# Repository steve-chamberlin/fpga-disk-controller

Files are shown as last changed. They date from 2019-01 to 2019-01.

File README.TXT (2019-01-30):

Compiled by Steve Chamberlin
steve@bigmessowires.com
January 28, 2019

//\\//\\//\\//\\//\\//\\//\\//\\//\\//\\//\\//\\//\\//\\//\\//\\//\\//\\//\\//\\

I'm sharing the FPGA disk controller design because I don't currently have the time or resources to pursue its further development on my own, but want the Apple II collector community to get the benefit of the progress I've made to date. 

See LICENSE.TXT for details on the license terms for this design.

The marks "Yellowstone", "BMOW", and "Big Mess o' Wires" are not covered by this license, and are reserved for my exclusive use. You are not permitted to use any of these words in the name of any clone or derivative products based on this design. You will need to choose a new name for your clone or derivative product.

//\\//\\//\\//\\//\\//\\//\\//\\//\\//\\//\\//\\//\\//\\//\\//\\//\\//\\//\\//\\

GROUND RULES
------------

Please don't send me detailed questions and requests for help with this design, or expect me to be your engineering consultant. I'm releasing the design to the community because I don't have time to pursue it myself. That means I can't work on it for you, either. The design is released as-is, with no promise of technical support. I may be able to answer general questions, but the rest is up to you.  

WHAT IS THIS?
-------------

Yellowstone is the code name for an Apple II disk controller card that's based on an FPGA, rather than using discrete logic chips and ROM chips. By reprogramming the FPGA, the card can be made to emulate various other disk controller cards made by Apple in the 1980s and 1990s. The work so far has focused on emulating an Apple Liron disk controller card, but it would also be easy to emulate a Disk II controller card. It's theoretically also possible to emulate a Disk 3.5 controller card, though this possibility has not been explored in detail.

WHAT'S LIRON?
-------------

The Liron disk controller was introduced by Apple in 1985. More formally known as the Apple II UniDisk 3.5 Controller, it's designed to work with a new generation of "smart" disk drives more sophisticated than the venerable Disk II 5.25 inch floppy drive. The smart disk port on the Liron is appropriately named the Smartport, and it can communicate with block-based storage devices such as the Unidisk 3.5 (an early 800K drive) and Smartport-based Apple II hard drives.

Why care about the Liron? The Apple IIc and Apple IIgs have integrated disk ports with built-in Smartport functionality, but for the earlier Apple II+ and IIe, the Liron is the only way to get a Smartport. For owners of the BMOW Floppy Emu disk emulator, having a Liron card makes it possible to use the Floppy Emu as an external hard drive for the II+ and IIe. Unfortunately finding a Liron is difficult, and although they occasionally turn up on eBay, they’re quite expensive. That makes cloning the Liron a desirable goal.

HOW IT WORKS
------------

The FPGA disk controller card is little more than an FPGA, a voltage regulator, and a set of level-shifting bus transceivers. The FPGA replaces all of the 7400-series discrete logic chips typically found on a disk controller card. Verilog (hardware description language) replacements for all of the 7400-series parts and other logic were written and programmed into the FPGA. This also includes a full Verilog implmentation of the Apple IWM chip. 

The FPGA also replaces the ROM chip containing the boot code for the card. The Apple II executes this code during power-up, and the code knows how to find and load sector 0 from the attached disk drive. The code was obtained from a ROM dump from a real Liron card.

The prototype card also includes a footprint for an 8-pin SPI flash memory chip. It is not used by the current FPGA code, and the chip can be omitted. The idea was that a small number of disk images could be stored in SPI flash memory, so the card could function both as a disk controller and as a disk emulator, but this was never implemented.

The card has a standard 10 x 2 pin disk connector on board. It can be connected directly to a BMOW Floppy Emu disk emulator, using a standard ribbon cable. But for a full Liron clone and connecton to a Unidisk 3.5, a DB-19 female connector is required. A design for a DB-19F adapter PCB is included here, and the adapter can be connected to the disk controller card with a short ribbon cable. The DB-19F is still available from surplus electronics suppliers in small quantities.

PROJECT STATUS
--------------

See https://www.bigmessowires.com/category/yellowstone/ for a complete history of work involving the FPGA disk controller.

The FPGA disk controller card was designed by Steve Chamberlin at Big Mess o' Wires during the summer of 2017, but the first prototype card wasn't built and tested until January 2018. The version 1.0 card had errors with the wiring for the output enable signal on one of the bus transceiver chips, and it required a few hand-soldered path wires to fix. After further development, the prototype card was demonstrated to work as a Liron clone, in both an Apple IIe enhanced computer and an Apple IIgs. It worked for controlling a real Unidisk 3.5 drive, as well as a BMOW Floppy Emu disk emulator configured for Smartport emulation mode.

Later testing discovered that the FPGA disk controller card worked reliably when it was the only card installed, but other cards were also present, it sometimes malfunctioned. The more other cards present, the worse the rate of errors became. This was diagnosed as a likely termination or contention problem on the Apple II data bus, and various fixes were tried unsuccessfully. After March 2018, I lost interest in researching the problem further, and no more work has occurred since then.

The design provided here is version 1.1, and it fixes the output enable problem from version 1.0.

WHERE TO START
--------------

Open the FPGA disk controller design (Liron clone) in EAGLE. Export Gerber files and send them to your favorite PCB fabricator. If desired, do the same for the DB19F adapter design.

Purchase the chips and other parts listed in the BOM. 

Assemble the card. I did it by hand, you can do it too. A syringe of solder paste and a hot plate or toaster oven works nicely.

Get a Lattice JTAG programmer or appropriate clone. Some clones don't handle 3.3V logic correctly. Maybe spend the extra money for a genuine Lattice programmer.

Install the Lattice Diamond software.

Apply 5V power to the card at jumper J4. Do not insert the card into your Apple II yet.

Program the FPGA with the bitstream for the Liron clone design - liron_fpgatop.jed

Insert the card in your Apple II. Remove any other cards that are present.

Connect a Smartport-compatible disk drive, such as a BMOW Floppy Emu disk emulator that's configured for Smartport emulation mode, or an Apple Unidisk 3.5 drive.

Turn on the Apple II. It should boot from the attached drive.

NEXT STEPS
----------

The bus termination or bus contention problem must be solved, in order to get a robust card that works smoothly when other cards are also present. See the blog posts from February-March 2018 for more details about what was already tried. A solution will require a person who's experienced at electronic design, and has appropriate test equipment such as an oscilloscope and logic analyzer.

The current design uses a Lattice MachXO2 1200HC FPGA, and a Lattice JTAG programmer (or compatible) is required for programming it. The XO2-1200HC has more logic resources than are actually necessary for the Liron clone design. The cheaper XO2-640 or XO2-256 could be substituted instead. They are mostly or entirely pin-compatible with the XO2-1200HC.

Programming the FPGA with a JTAG programmer is fine for development use, but end users are unlikely to have one. If reprogramming by the end user is desired (say to switch between Liron and Disk 3.5 emulation behaviors), a different method of FPGA programming will need to be developed.

FILES
-----

eagle/ - directory containing EAGLE designs for the FPGA disk controller card, the DB19F adapter, and a reverse-engineered schematic of the original Liron card.
eagle/FPGA disk controller/bom.xslx - bill of materials needed to assemble the card.
lattice/ - directory containing the Verilog and other code for the Liron clone design for the card.
yellowstone_blink/ - directory containing the Verilog and other code for a simple LED blink example. This can be used to verify that the FPGA is working.
yellowstone_blink_tcr.dir/ - directory containing some junk generated by the Lattice Diamond software.
disasm.asm, liron.asm - two different disassemblies of the original Liron card's boot ROM
LIRONALL.BIN - binary file with the original Liron card's boot ROM
rom-full-4k.mem - the Liron boot ROM in a format compatible with the Lattice Diamond software.
README.TXT - this file
LICENSE.TXT - details about the license for the design

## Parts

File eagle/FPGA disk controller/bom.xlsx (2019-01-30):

Designation | Description | Manufacturer Part Number | Acceptable Substitutes | Source 1 | Source 2 | notes
U1 | MachXO2 1200HC FPGA, 100-pin TQFP package | Lattice LCMXO2-1200HC-4TG100C | none | https://www.digikey.com/product-detail/en/lattice-semiconductor-corporation/LCMXO2-1200HC-4TG100C/220-1282-ND/2764797 |  | Could downsize to XO2-640 or XO2-256 if extra ROM space isn't needed. Confirm pinout differences.
U2 | SPI Flash memory, 8-pin SIOC package | Adesto AT25SF161-SSHD-T | similar | https://www.digikey.com/product-detail/en/adesto-technologies/AT25SF161-SSHD-T/1265-1230-1-ND/6124886 |  | Optional. Use for disk image storage, or ROM code if it's fast enough.
U3 | 300mA 3.3V LDO regulator, 5V input, SOT235 package | Micrel MIC5504-3.3YM5-TR | similar | https://www.digikey.com/product-detail/en/microchip-technology/MIC5504-3.3YM5-TR/576-4764-1-ND/4864028 | https://www.arrow.com/en/products/mic5504-3.3ym5-tr/microchip-technology
U4,U5,U6,U7 | 8-bit bus transceiver 74LVC245 | Nexperia 74LVC245ADB,118 | similar | https://www.digikey.com/product-detail/en/nexperia-usa-inc/74LVC245ADB,118/1727-3079-1-ND/946736
CON1 | IDC-20 male shrouded header | On Shore Technology 302-S201 | generic | http://www.digikey.com/product-detail/en/302-S201/ED10524-ND/2794235 | http://www.digikey.com/product-detail/en/SBH11-PBPC-D10-ST-BK/S9172-ND/1990065
J1 | 6x1 pin 0.1 inch male header, PTH | MC34743 | generic | http://www.newark.com/multicomp/mc34743/board-board-connector-header-24/dp/08N6756 | https://www.digikey.com/product-detail/en/sullins-connector-solutions/PRPC040SAAN-RC/S1011EC-40-ND/2775214 | Optional, JTAG port.
J2 | 4x1 pin 0.1 inch male header, PTH | MC34743 | generic | http://www.newark.com/multicomp/mc34743/board-board-connector-header-24/dp/08N6756 | https://www.digikey.com/product-detail/en/sullins-connector-solutions/PRPC040SAAN-RC/S1011EC-40-ND/2775214 | Optional, SPI port.
J3 | 8x1 pin 0.1 inch male header, PTH | MC34743 | generic | http://www.newark.com/multicomp/mc34743/board-board-connector-header-24/dp/08N6756 | https://www.digikey.com/product-detail/en/sullins-connector-solutions/PRPC040SAAN-RC/S1011EC-40-ND/2775214 | Optional, debug port.
J4 | 2x1 pin 0.1 inch male header, PTH | MC34743 | generic | http://www.newark.com/multicomp/mc34743/board-board-connector-header-24/dp/08N6756 | https://www.digikey.com/product-detail/en/sullins-connector-solutions/PRPC040SAAN-RC/S1011EC-40-ND/2775214 | Optional, 5V supply connector
D1 | LED, green, 0805 package, about 12 mcd | KP-2012SGC | generic | http://www.newark.com/kingbright/kp-2012sgc/led-green-1-25mm-x-1-3mm-15mcd/dp/31M5189 | https://www.digikey.com/product-detail/en/osram-opto-semiconductors-inc/LG-R971-KN-1/475-1410-1-ND/1802598 | debug LED
L1 | ferrite bead 0805 | BKP2125HS600-T | generic | https://www.digikey.com/product-detail/en/taiyo-yuden/BKP2125HS600-T/587-1932-1-ND/1465402
R1,R2 | 390 ohm resistor, 0805 package, 1/8W, 20% | RMCF0805JT390R | generic | https://www.digikey.com/product-detail/en/stackpole-electronics-inc/RMCF0805JT390R/RMCF0805JT390RCT-ND/1942549
R3 | 4.7K ohm resistor, 0805 package, 1/8W, 20% | RMCF0805JT4K70 | generic | https://www.digikey.com/product-detail/en/stackpole-electronics-inc/RMCF0805JT4K70/RMCF0805JT4K70CT-ND/1942570
R4,R5,R6 | 22K ohm resistor, 0805 package, 1/8W, 20% | RMCF0805JT22K0 | generic | https://www.digikey.com/product-detail/en/stackpole-electronics-inc/RMCF0805JT22K0/RMCF0805JT22K0CT-ND/1942581
C1-C12 | 0.1uF ceramic capacitor, 0805 package, 50V, 20% | CL21B104MBCNNNC | generic | https://www.digikey.com/product-detail/en/samsung-electro-mechanics-america-inc/CL21B104MBCNNNC/1276-2450-1-ND/3890536
C13-C18 | 0.01uF ceramic capacitor, 0805 package, 50V, 20% | CL21B103KBANNNC | generic | https://www.digikey.com/product-detail/en/samsung-electro-mechanics-america-inc/CL21B103KBANNNC/1276-1015-1-ND/3889101
C19,C20 | 10uF ceramic capacitor, 0805 package, 6.3V, 20% | CL21A106KQCLRNC | generic | http://www.newark.com/avx/08056d106kat2a/ceramic-capacitor-10uf-6-3v-x5r/dp/84K8398 | https://www.digikey.com/product-detail/en/samsung-electro-mechanics-america-inc/CL21A106KQCLRNC/1276-2405-1-ND/3890491
MISC1 | DB19-F |  |  |  |  | not required for Floppy Emu, but required for real drives
MISC2 | DB19-F adapter board |  |  |  |  | not required for Floppy Emu, but required for real drives

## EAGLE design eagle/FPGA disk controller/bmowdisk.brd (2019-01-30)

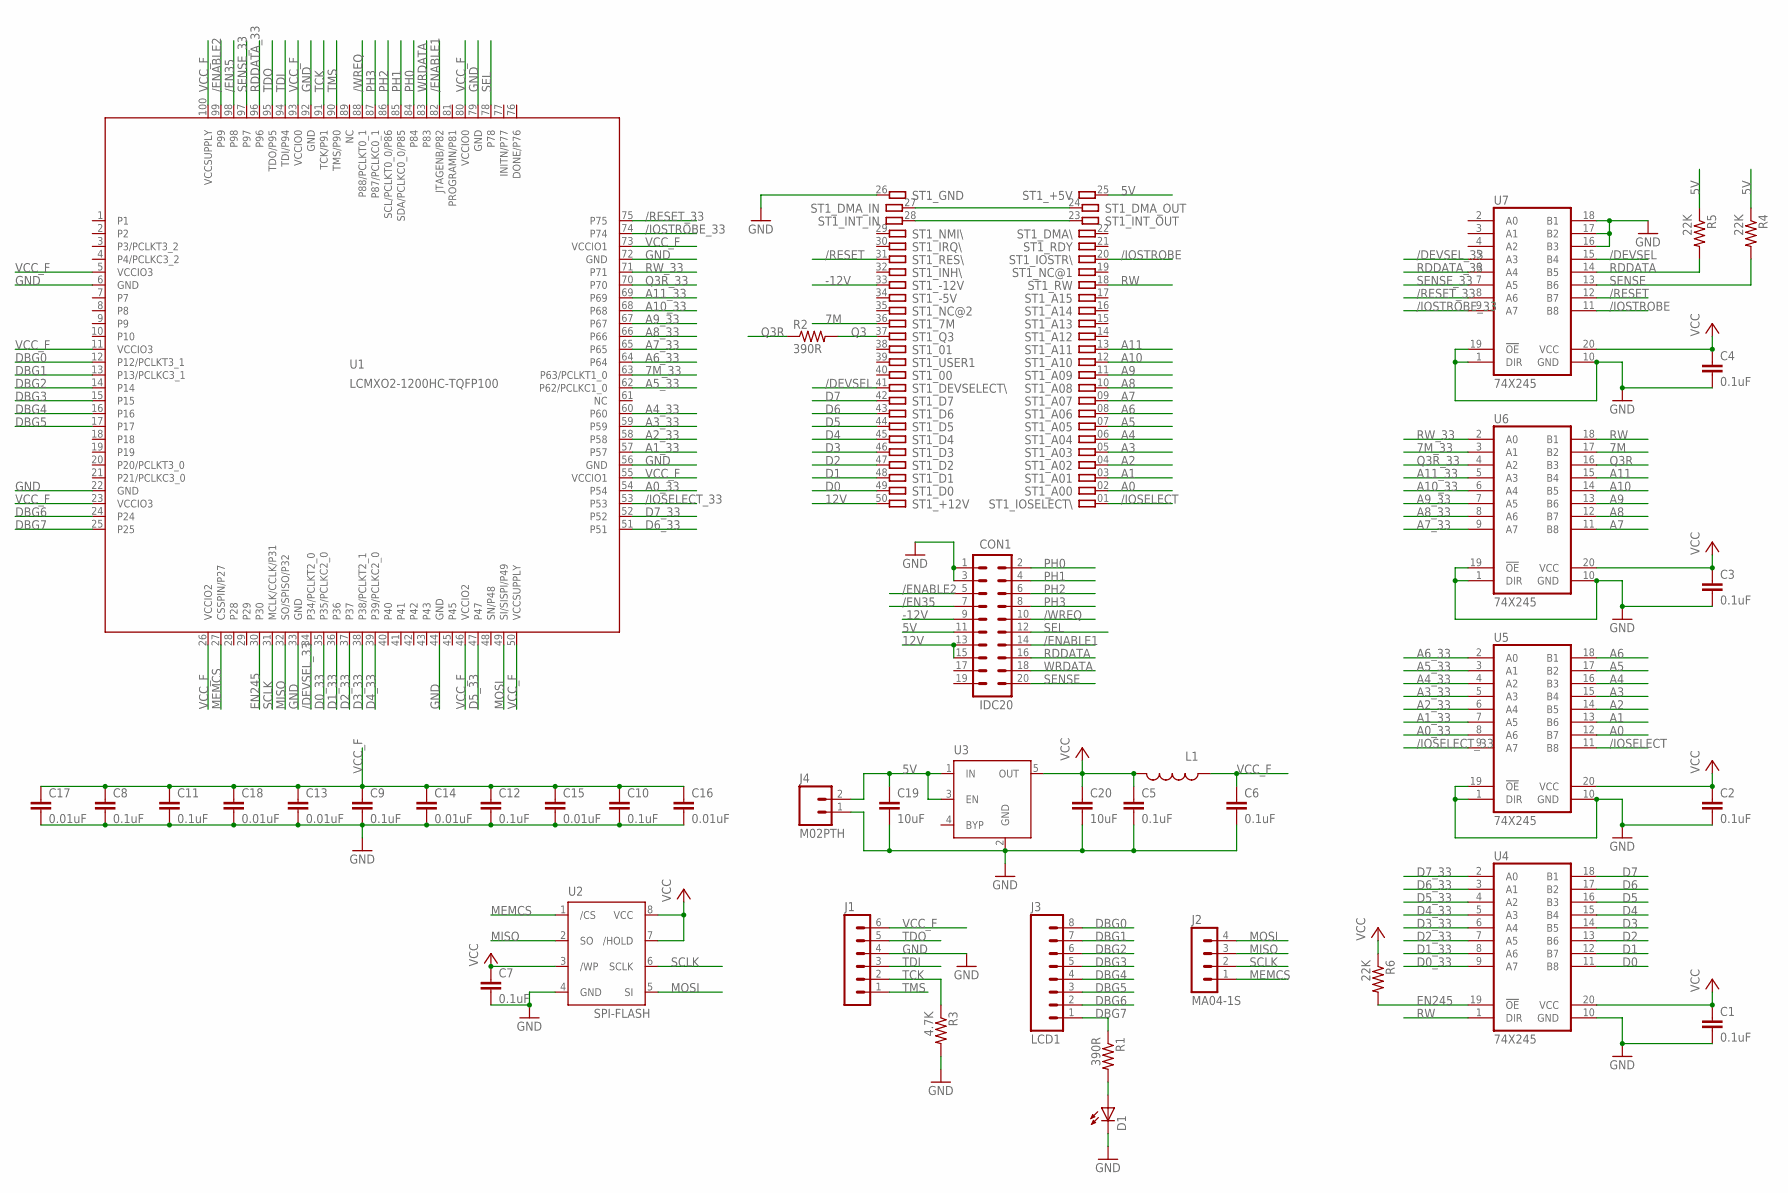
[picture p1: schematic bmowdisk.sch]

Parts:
C1, C2, C3, C4, C5, C6, C7, C8, C9, C10, C11, C12: 0.1uF; 0805
C13, C14, C15, C16, C17, C18: 0.01uF; 0805
C19, C20: 10uF; 0805
CON1: IDC20
D1: LEDCHIP-LED0805; CHIP-LED0805
J1: MA06-1NORMAL; MA06-1
J2: MA04-1S; MA04-1
J3: LCD1; 1X08
J4: M02PTH; 1X02
L1: INDUCTOR0805; 0805
R1, R2: 390R; 0805
R3: 4.7K; 0805
R4, R5, R6: 22K; 0805
ST1: A2-50PINMINI; A2-50PIN-MINI
U1: LCMXO2-1200HC-TQFP100; TQFP100
U2: SPI-FLASH; SOIC08
U3: MIC5219XX; SOT23-5
U4, U5, U6, U7: 74X245; SSOP20

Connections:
5V: C19.1, CON1.11, J4.2, R4.1, R5.1, ST1.25, U3.1 (IN), U3.3 (EN)
7M: ST1.36, U6.17 (B2)
7M_33: U1.63 (P63/PCLKT1_0), U6.3 (A1)
12V: CON1.13, CON1.15, ST1.50
-12V: CON1.9, ST1.33
/DEVSEL: ST1.41, U7.15 (B4)
/DEVSEL_33: U1.34 (P34/PCLKT2_0), U7.5 (A3)
/EN35: CON1.7, U1.98
/ENABLE1: CON1.14, U1.82 (JTAGENB/P82)
/ENABLE2: CON1.5, U1.99
/IOSELECT: ST1.01, U5.11 (B8)
/IOSELECT_33: U1.53, U5.9 (A7)
/IOSTROBE: ST1.20, U7.11 (B8)
/IOSTROBE_33: U1.74, U7.9 (A7)
/RESET: ST1.31, U7.12 (B7)
/RESET_33: U1.75, U7.8 (A6)
/WREQ: CON1.10, U1.88 (P88/PCLKT0_1)
A0: ST1.02, U5.12 (B7)
A0_33: U1.54, U5.8 (A6)
A1: ST1.03, U5.13 (B6)
A1_33: U1.57, U5.7 (A5)
A2: ST1.04, U5.14 (B5)
A2_33: U1.58, U5.6 (A4)
A3: ST1.05, U5.15 (B4)
A3_33: U1.59, U5.5 (A3)
A4: ST1.06, U5.16 (B3)
A4_33: U1.60, U5.4 (A2)
A5: ST1.07, U5.17 (B2)
A5_33: U1.62 (P62/PCLKC1_0), U5.3 (A1)
A6: ST1.08, U5.18 (B1)
A6_33: U1.64, U5.2 (A0)
A7: ST1.09, U6.11 (B8)
A7_33: U1.65, U6.9 (A7)
A8: ST1.10, U6.12 (B7)
A8_33: U1.66, U6.8 (A6)
A9: ST1.11, U6.13 (B6)
A9_33: U1.67, U6.7 (A5)
A10: ST1.12, U6.14 (B5)
A10_33: U1.68, U6.6 (A4)
A11: ST1.13, U6.15 (B4)
A11_33: U1.69, U6.5 (A3)
D0: ST1.49, U4.11 (B8)
D0_33: U1.35 (P35/PCLKC2_0), U4.9 (A7)
D1: ST1.48, U4.12 (B7)
D1_33: U1.36, U4.8 (A6)
D2: ST1.47, U4.13 (B6)
D2_33: U1.37, U4.7 (A5)
D3: ST1.46, U4.14 (B5)
D3_33: U1.38 (P38/PCLKT2_1), U4.6 (A4)
D4: ST1.45, U4.15 (B4)
D4_33: U1.39 (P39/PCLKC2_0), U4.5 (A3)
D5: ST1.44, U4.16 (B3)
D5_33: U1.47, U4.4 (A2)
D6: ST1.43, U4.17 (B2)
D6_33: U1.51, U4.3 (A1)
D7: ST1.42, U4.18 (B1)
D7_33: U1.52, U4.2 (A0)
DBG0: J3.8, U1.12 (P12/PCLKT3_1)
DBG1: J3.7, U1.13 (P13/PCLKC3_1)
DBG2: J3.6, U1.14
DBG3: J3.5, U1.15
DBG4: J3.4, U1.16
DBG5: J3.3, U1.17
DBG6: J3.2, U1.24
DBG7: J3.1, R1.1, U1.25
EN245: R6.2, U1.30, U4.19 (!OE)
GND: C1.2, C2.2, C3.2, C4.2, C5.2, C6.2, C7.2, C8.2, C9.2, C10.2, C11.2, C12.2, C13.2, C14.2, C15.2, C16.2, C17.2, C18.2, C19.2, C20.2, CON1.1, CON1.3, D1.C, J1.4, J4.1, R3.2, ST1.26, U1.6 (GND), U1.22 (GND), U1.33 (GND), U1.44 (GND), U1.56 (GND), U1.72 (GND), U1.79 (GND), U1.92 (GND), U2.4 (GND), U3.2 (GND), U4.10 (GND), U5.1 (DIR), U5.10 (GND), U5.19 (!OE), U6.1 (DIR), U6.10 (GND), U6.19 (!OE), U7.1 (DIR), U7.10 (GND), U7.16 (B3), U7.17 (B2), U7.18 (B1), U7.19 (!OE)
MEMCS: J2.1, U1.27 (CSSPIN/P27), U2.1 (/CS)
MISO: J2.3, U1.32 (SO/SPISO/P32), U2.2 (SO)
MOSI: J2.4, U1.49 (SI/SISPI/P49), U2.5 (SI)
unnamed: ST1.24, ST1.27
unnamed: ST1.23, ST1.28
unnamed: D1.A, R1.2
PH0: CON1.2, U1.84
PH1: CON1.4, U1.85 (SDA/PCLKC0_0/P85)
PH2: CON1.6, U1.86 (SCL/PCLKT0_0/P86)
PH3: CON1.8, U1.87 (P87/PCLKC0_1)
Q3: R2.2, ST1.37
Q3R: R2.1, U6.16 (B3)
Q3R_33: U1.70, U6.4 (A2)
RDDATA: CON1.16, R5.2, U7.14 (B5)
RDDATA_33: U1.96, U7.6 (A4)
RW: ST1.18, U4.1 (DIR), U6.18 (B1)
RW_33: U1.71, U6.2 (A0)
SCLK: J2.2, U1.31 (MCLK/CCLK/P31), U2.6 (SCLK)
SEL: CON1.12, U1.78
SENSE: CON1.20, R4.2, U7.13 (B6)
SENSE_33: U1.97, U7.7 (A5)
TCK: J1.2, R3.1, U1.91 (TCK/P91)
TDI: J1.3, U1.94 (TDI/P94)
TDO: J1.5, U1.95 (TDO/P95)
TMS: J1.1, U1.90 (TMS/P90)
VCC: C1.1, C2.1, C3.1, C4.1, C5.1, C7.1, C20.1, L1.2, R6.1, U2.3 (/WP), U2.7 (/HOLD), U2.8 (VCC), U3.5 (OUT), U4.20 (VCC), U5.20 (VCC), U6.20 (VCC), U7.20 (VCC)
VCC_F: C6.1, C8.1, C9.1, C10.1, C11.1, C12.1, C13.1, C14.1, C15.1, C16.1, C17.1, C18.1, J1.6, L1.1, U1.5 (VCCIO3), U1.11 (VCCIO3), U1.23 (VCCIO3), U1.26 (VCCIO2), U1.46 (VCCIO2), U1.50 (VCCSUPPLY), U1.55 (VCCIO1), U1.73 (VCCIO1), U1.80 (VCCIO0), U1.93 (VCCIO0), U1.100 (VCCSUPPLY)
WRDATA: CON1.18, U1.83

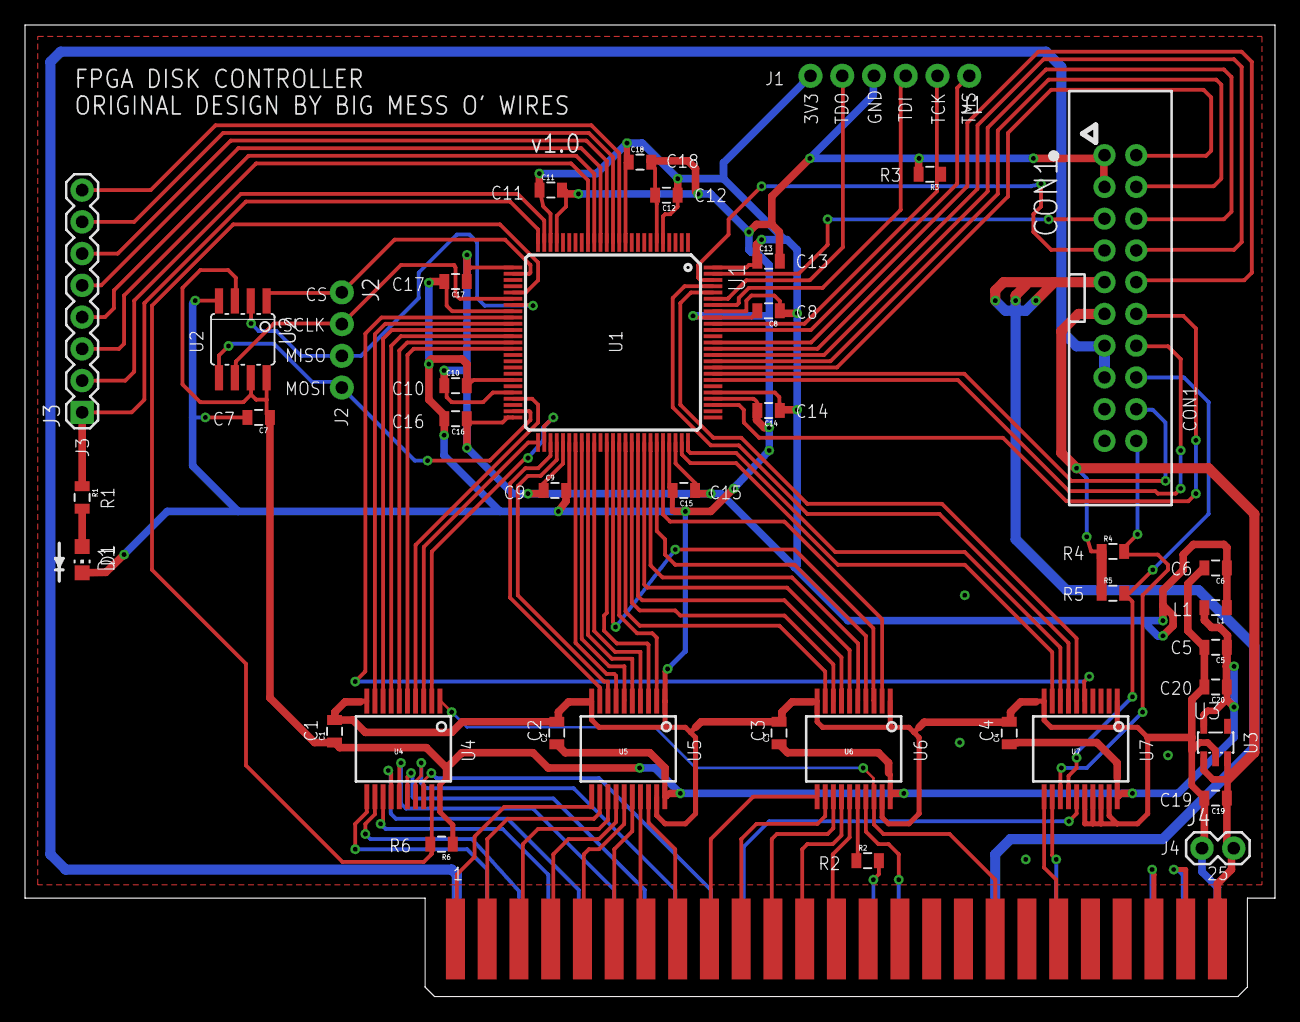
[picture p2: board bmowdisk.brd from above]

Board: 2 copper layers, 100.0 x 77.7 mm, 41 parts (0 on the bottom side), 95 nets.

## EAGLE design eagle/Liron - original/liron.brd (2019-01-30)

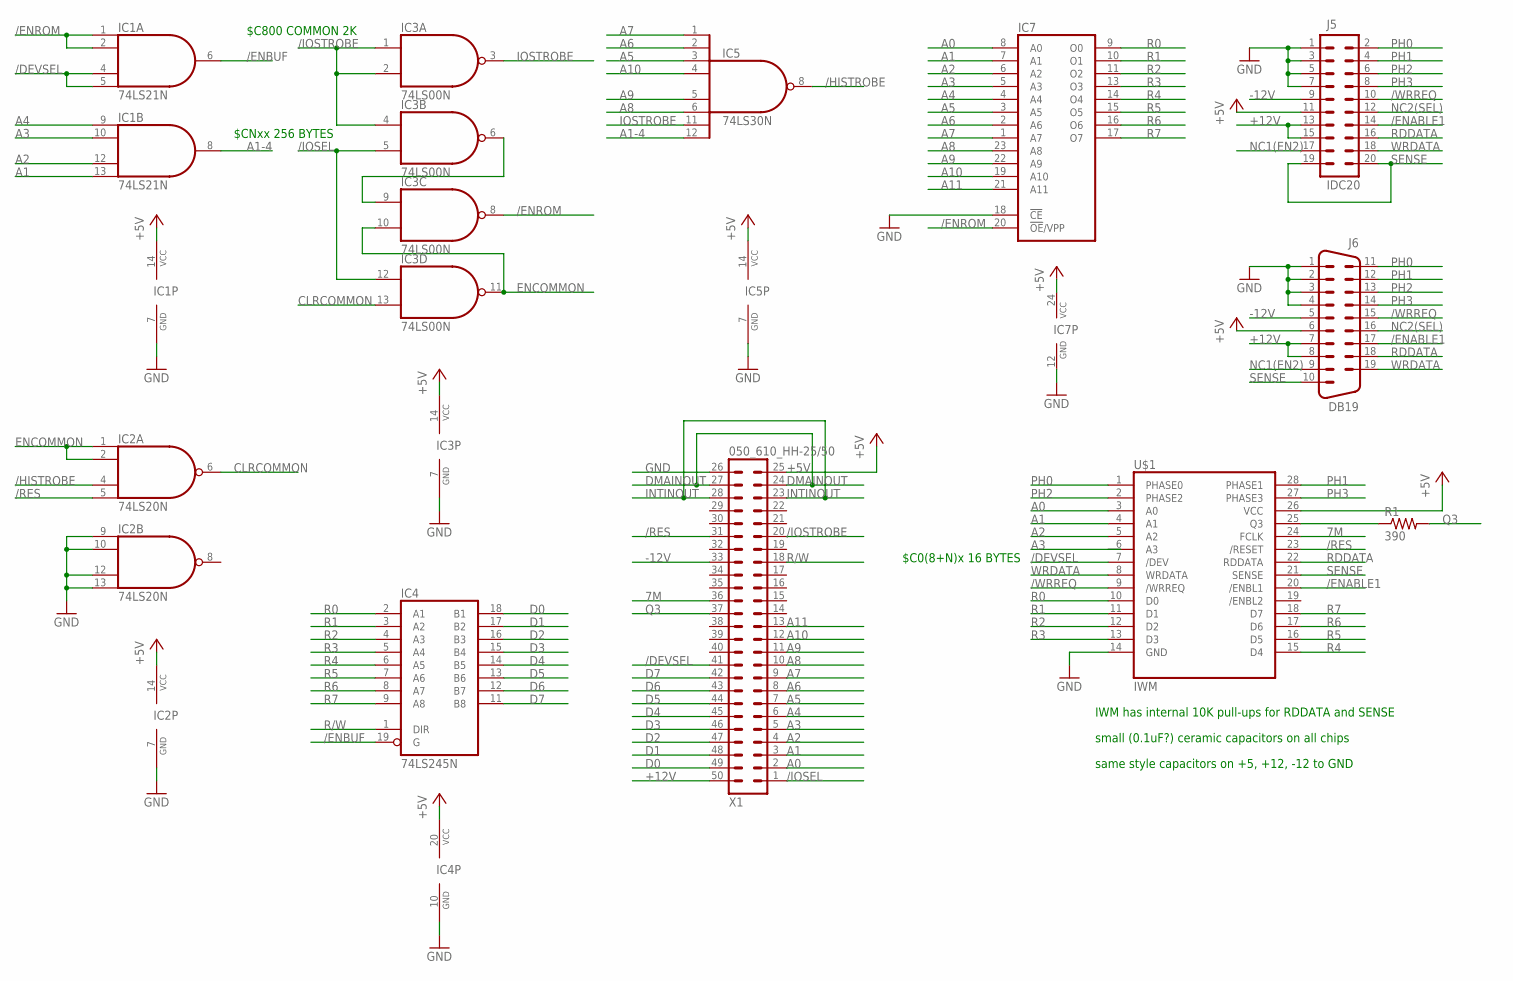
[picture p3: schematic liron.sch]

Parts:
IC1: 74LS21N; DIL14
IC2: 74LS20N; DIL14
IC3: 74LS00N; DIL14
IC4: 74LS245N; DIL20
IC5: 74LS30N; DIL14
IC7: 2732; DIL24
J5: IDC20
J6: DB19; DB19EDGE
R1: 390; 0805
U$1: IWM; DIL28
X1: 050_610_HH-25/50

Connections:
7M: U$1.24 (FCLK), X1.36 (40)
+5V: IC1.14 (VCC), IC2.14 (VCC), IC3.14 (VCC), IC4.20 (VCC), IC5.14 (VCC), IC7.24 (VCC), J5.11, J6.6, U$1.26 (VCC), X1.25
+12V: J5.13, J5.15, J6.7, J6.8, X1.50 (26)
-12V: J5.9, J6.5, X1.33 (43)
/DEVSEL: IC1.4 (I2), IC1.5 (I3), U$1.7 (/DEV), X1.41 (35)
/ENABLE1: J5.14, J6.17, U$1.20 (/ENBL1)
/ENBUF: IC1.6 (O), IC4.19 (G)
/ENROM: IC1.1 (I0), IC1.2 (I1), IC3.8 (O), IC7.20 (!OE!/VPP)
/HISTROBE: IC2.4 (I2), IC5.8 (O)
/IOSEL: IC3.5 (I1), IC3.12 (I0), X1.1
/IOSTROBE: IC3.1 (I0), IC3.2 (I1), IC3.4 (I0), X1.20
/RES: IC2.5 (I3), U$1.23 (/RESET), X1.31 (45)
/WRREQ: J5.10, J6.15, U$1.9 (/WRREQ)
A0: IC7.8 (A0), U$1.3 (A0), X1.2
A1: IC1.13 (I3), IC7.7 (A1), U$1.4 (A1), X1.3
A1-4: IC1.8 (O), IC5.12 (I7)
A2: IC1.12 (I2), IC7.6 (A2), U$1.5 (A2), X1.4
A3: IC1.10 (I1), IC7.5 (A3), X1.5
A4: IC1.9 (I0), IC7.4 (A4), X1.6
A5: IC5.3 (I2), IC7.3 (A5), X1.7
A6: IC5.2 (I1), IC7.2 (A6), X1.8
A7: IC5.1 (I0), IC7.1 (A7), X1.9
A8: IC5.6 (I5), IC7.23 (A8), X1.10
A9: IC5.5 (I4), IC7.22 (A9), X1.11
A10: IC5.4 (I3), IC7.19 (A10), X1.12
A11: IC7.21 (A11), X1.13
CLRCOMMON: IC2.6 (O), IC3.13 (I1)
D0: IC4.18 (B1), X1.49 (27)
D1: IC4.17 (B2), X1.48 (28)
D2: IC4.16 (B3), X1.47 (29)
D3: IC4.15 (B4), X1.46 (30)
D4: IC4.14 (B5), X1.45 (31)
D5: IC4.13 (B6), X1.44 (32)
D6: IC4.12 (B7), X1.43 (33)
D7: IC4.11 (B8), X1.42 (34)
DMAINOUT: X1.24, X1.27 (49)
ENCOMMON: IC2.1 (I0), IC2.2 (I1), IC3.10 (I1), IC3.11 (O)
GND: IC1.7 (GND), IC2.7 (GND), IC2.9 (I0), IC2.10 (I1), IC2.12 (I2), IC2.13 (I3), IC3.7 (GND), IC4.10 (GND), IC5.7 (GND), IC7.12 (GND), IC7.18 (!CE), J5.1, J5.3, J5.5, J5.7, J6.1, J6.2, J6.3, J6.4, U$1.14 (GND), X1.26 (50)
INTINOUT: X1.23, X1.28 (48)
IOSTROBE: IC3.3 (O), IC5.11 (I6)
unnamed: IC3.6 (O), IC3.9 (I0)
unnamed: R1.1, U$1.25 (Q3)
NC1(EN2): J5.17, J6.9
NC2(SEL): J5.12, J6.16
PH0: J5.2, J6.11, U$1.1 (PHASE0)
PH1: J5.4, J6.12, U$1.28 (PHASE1)
PH2: J5.6, J6.13, U$1.2 (PHASE2)
PH3: J5.8, J6.14, U$1.27 (PHASE3)
Q3: R1.2, X1.37 (39)
R0: IC4.2 (A1), IC7.9 (O0), U$1.10 (D0)
R1: IC4.3 (A2), IC7.10 (O1), U$1.11 (D1)
R2: IC4.4 (A3), IC7.11 (O2), U$1.12 (D2)
R3: IC4.5 (A4), IC7.13 (O3), U$1.13 (D3)
R4: IC4.6 (A5), IC7.14 (O4), U$1.15 (D4)
R5: IC4.7 (A6), IC7.15 (O5), U$1.16 (D5)
R6: IC4.8 (A7), IC7.16 (O6), U$1.17 (D6)
R7: IC4.9 (A8), IC7.17 (O7), U$1.18 (D7)
R/W: IC4.1 (DIR), X1.18
RDDATA: J5.16, J6.18, U$1.22 (RDDATA)
SENSE: J5.19, J5.20, J6.10, U$1.21 (SENSE)
WRDATA: J5.18, J6.19, U$1.8 (WRDATA)

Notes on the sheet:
$C800 COMMON 2K
$CNxx 256 BYTES
$C0(8+N)x 16 BYTES
small (0.1uF?) ceramic capacitors on all chips
same style capacitors on +5, +12, -12 to GND
IWM has internal 10K pull-ups for RDDATA and SENSE

Board: 2 copper layers, 11 parts (0 on the bottom side), 61 nets, no tracks yet.

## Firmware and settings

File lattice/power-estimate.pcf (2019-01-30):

[[Info]]
_PARENT: none
_FAMILY: xo2c00
_FILE_FORMAT: 1.00
_DATA_VALUES: 1.00
_STATUS: Advanced

[[Project]]
DesignName: top
Family: MachXO2
Device: LCMXO2-640HC
Package: TQFP100
Operating: Commercial
Version: 8.0
Performance: -4
PartName: LCMXO2-640HC-4TG100C

[[Settings]]
EstimationMode: Medium
ProcessType: Typical
SoftwareMode: Calculation
TempAmbX: Ambient Temperature
SectionY: Total Power
SectionX: Vcc
SectionLowerLimit: 0.0000
SectionUpperLimit: 0.0000
SectionResolution: 0.0000
TempAmbY: Ambient Temperature
TempAmbLowerLimit: -30.0000
TempAmbUpperLimit: 115.0000
TempAmbResolution: 29.0000
FreqY: Total Power
FreqX: No Clocks Found!
FreqLowerLimit: 10.0000
FreqUpperLimit: 100.0000
FreqAmbResolution: 20.0000
PowerMode: Normal
DisableBandgap: false
DisablePor: false
DisableDll: false
DisableOsc: false
DisablePLL0: false
DisablePLL1: false
DisableInRd0: false
DisableInRd1: false
DisableInRd2: false
DisableInRd3: false
DisableInRd4: false
DisableInRd5: false
DisableInRd6: false
DisableInRd7: false
EnablePg0: false
EnablePg1: false
EnablePg2: false
EnablePg3: false
EnablePg4: false
EnablePg5: false
EnablePg6: false
EnablePg7: false
DisableLVDS: false
DisableLVDS1: false
DisableLVDS2: false
DisableLVDS3: false
DisableLVDS4: false
DisableLVDS5: false
DisableLVDS6: false
DisableLVDS7: false

[[Thermal]]
Airflow: 200 LFM
AmbientTemperature: 25
CustomThetaSA: -1
JunctionTemperature: 25.19
MaxSafeAmbient: 84.67
ThetaBA: 10.0
ThetaCS: 0
ThetaEffective: 16.65
ThetaJA: 20.59
ThetaJB: 12.88
ThetaJC: 0
ThetaSA: -1
UserThetaBA: No
UserThetaCS: No
UserThetaEffective: No
UserThetaJA: No
UserThetaJB: No
UserThetaJC: No
UserThetaSA: No
thetaBoard: Medium Board
thetaHeatSink: No Heat Sink
thetaOption: ThermalModels

[[VDPM]]
Supply = Voltage, DPM
Vcc = 3.300, 1.00
Vccio 3.3 = 3.300, 1.00
Vccio 2.5 = 2.500, 1.00
Vccio 1.8 = 1.800, 1.00
Vccio 1.5 = 1.500, 1.00
Vccio 1.2 = 1.200, 1.00

[[Logic]]
Clk = F, AF, LUT, RAM, RIPPLE, REG, X0, X1, X2, X6, ISB, ISBLUT, ISBCE, ISBLSR, ISBM, ISBCLK
COMBINATORIAL = 7.0000, 10.0000^d^, 56, 0, 0, 0, 59, 23, 123, 31, 119, 70, 16, 6, 9, 2
_devsel_c = 1.0000, 10.0000^d^, 15, 0, 0, 8, 18, 18, 55, 9, 61, 49, 8, 3, 1, 8
fclk_c = 7.0000, 10.0000^d^, 43, 0, 0, 35, 50, 25, 66, 18, 301, 290, 5, 5, 1, 23

[[Clocks]]
Clk = F, Duty, Pfeed, Ptrunk, Pspine, Ptap, Pbranch, Strunk, Sspine, Stap, Sbranch, Etb, Ebg, Elr
_devsel_c = 1.0000, 50.0000, 0, 0, 0, 0, 0, t4_1, c13_1, r4_2, b_10, 0, 0, 0
fclk_c = 7.0000, 50.0000, 0, t3_1, s13_1, p13_1_p17_1, c14_4_c17_4, 0, 0, 0, b_0, 0, 0, 0

[[Input Output]]
Clk = _Type, _Mode, F, AF, IP, OP, PG, Cload, Bank, _ActualMode, _Pull, X0, X1, X2, X6, ISB
COMBINATORIAL = LVCMOS25, none, 7.0000, 10.0000^d^, 4, 0, OFF, 5, 2, none, DOWN, 0, 0, 0, 0, 0
COMBINATORIAL = LVCMOS25, none, 7.0000, 10.0000^d^, 11, 0, OFF, 5, 1, none, DOWN, 0, 0, 0, 0, 0
COMBINATORIAL = LVCMOS25, none, 7.0000, 10.0000^d^, 5, 0, OFF, 5, 0, none, DOWN, 0, 0, 0, 0, 0
COMBINATORIAL = LVCMOS25-8mA-SLEW:SLOW, none, 7.0000, 10.0000^d^, 0, 2, N/A, 5, 2, none, DOWN, 0, 0, 0, 0, 0
_devsel_c = LVCMOS25-8mA-SLEW:SLOW, none, 1.0000, 10.0000^d^, 0, 1, N/A, 5, 1, none, DOWN, 0, 0, 0, 0, 0
_devsel_c = LVCMOS25-8mA-SLEW:SLOW, none, 1.0000, 10.0000^d^, 0, 2, N/A, 5, 0, none, DOWN, 0, 0, 0, 0, 0
_devsel_c = LVCMOS25-8mA-SLEW:SLOW, none, 1.0000, 10.0000^d^, 0, 4, N/A, 5, 3, none, DOWN, 0, 0, 0, 0, 0
_devsel_c = LVCMOS25-8mA-SLEW:SLOW, none, 1.0000, 10.0000^d^, 0, 10, N/A, 5, 2, none, DOWN, 0, 0, 0, 0, 0
_devsel_c = LVCMOS25, none, 1.0000, 10.0000^d^, 1, 0, OFF, 5, 3, none, UP, 0, 0, 0, 0, 0
fclk_c = LVCMOS25-8mA-SLEW:SLOW, none, 7.0000, 10.0000^d^, 0, 1, N/A, 5, 0, none, DOWN, 0, 0, 0, 0, 0
fclk_c = LVCMOS25, none, 7.0000, 10.0000^d^, 1, 0, OFF, 5, 2, none, DOWN, 0, 0, 0, 0, 0

[[Bidi]]
ClkInpName = _Type, _Mode, InpF, InpAF, Bidi, PG, ClkOutName, OutF, OutAF, Duty, Cload, Bank, _ActualMode, _Pull, X0, X1, X2, X6, ISB
COMBINATORIAL = LVCMOS25-8mA-SLEW:SLOW, none, 7.0000, 10.0000^d^, 5, OFF, N/A, 0.0000^d^, 10.0000^d^, 50, 5, 1, none, DOWN, 0, 0, 0, 0, 0
_devsel_c = LVCMOS25-8mA-SLEW:SLOW, none, 1.0000, 10.0000^d^, 3, OFF, N/A, 0.0000^d^, 10.0000^d^, 50, 5, 1, none, DOWN, 0, 0, 0, 0, 0

[[Bank Voltage]]
Bank = Voltage, InRD, LVDSO, PG
0 = Vccio 2.5, No, No, OFF
1 = Vccio 2.5, No, N/A, OFF
2 = Vccio 2.5, No, N/A, OFF
3 = Vccio 2.5, No, N/A, OFF

[[Termination]]
_Type = IP, OP, Bidi, Duty, Bank, Rth, Vth
LVCMOS25 = 5, 0, 0, 0.0, 2, 1.0E12, 0
LVCMOS25 = 11, 0, 0, 0.0, 1, 1.0E12, 0
LVCMOS25 = 5, 0, 0, 0.0, 0, 1.0E12, 0
LVCMOS25-8mA-SLEW:SLOW = 0, 12, 0, 0.0, 2, 1.0E12, 0
LVCMOS25-8mA-SLEW:SLOW = 0, 1, 8, 31.8, 1, 1.0E12, 0
LVCMOS25-8mA-SLEW:SLOW = 0, 3, 0, 0.0, 0, 1.0E12, 0
LVCMOS25-8mA-SLEW:SLOW = 0, 4, 0, 0.0, 3, 1.0E12, 0
LVCMOS25 = 1, 0, 0, 0.0, 3, 1.0E12, 0

[[SP RAM]]
Clk = EBR, F, AF, _Type, X0, X1, X2, X6, ISB

[[DP RAM]]
RdClk = RdF, RdAF, EBR, WrClk, WrF, WrAF, _TypeA, _TypeB, X0, X1, X2, X6, ISB
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

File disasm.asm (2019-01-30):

L0000   = $0000
L0001   = $0001
L0002   = $0002
L0003   = $0003
L0024   = $0024
L0025   = $0025
L0040   = $0040
L0041   = $0041
L0042   = $0042
L0043   = $0043
L0044   = $0044
L0045   = $0045
L0046   = $0046
L0047   = $0047
L0048   = $0048
L0049   = $0049
L004B   = $004B
L004C   = $004C
L004D   = $004D
L004E   = $004E
L004F   = $004F
L0050   = $0050
L0051   = $0051
L0052   = $0052
L0053   = $0053
L0054   = $0054
L0055   = $0055
L0056   = $0056
L0057   = $0057
L0058   = $0058
L0059   = $0059
L005A   = $005A
L005B   = $005B
L0083   = $0083
L00A0   = $00A0
L00B9   = $00B9
L00C2   = $00C2
L00C4   = $00C4
L00C5   = $00C5
L00C9   = $00C9
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
LA0C5   = $A0C5
LA0CF   = $A0CF
LAEE3   = $AEE3
LD4CF   = $D4CF
LE000   = $E000
LF5F0   = $F5F0
LFABA   = $FABA
LFC22   = $FC22
LFDED   = $FDED
LFE89   = $FE89
LFE93   = $FE93

 .org $C700
        LDX     #$20
        LDX     #$00
        LDX     #$03
        CMP     #$00
        BCS     LC714

        SEC
        BCS     LC70E

        CLC
.LC70E
        LDX     #$07
        ROR     L0478,X
        CLC
.LC714
        LDX     #$C7
        STX     L07F8
        LDX     #$07
        LDA     LCFFF
        JMP     LCBE1

        LDY     #$00
        LDA     L004B
        PHA
        BNE     LC72B

        JMP     LC7B8

.LC72B
        LDA     LC0FC
        BPL     LC72B

        STA     L0059
        LSR     A
        LSR     A
        LSR     A
        AND     #$0F
        TAX
        LDA     L0059
        AND     #$07
        STA     L0059
.LC73E
        LDA     LC0FC
        BPL     LC73E

        EOR     LCA27,X
        STA     (L0056),Y
        EOR     L0040
        STA     L0040
        INY
        BNE     LC751

        INC     L0057
.LC751
        LDA     LC0FC
        BPL     LC751

        EOR     LCA37,X
        STA     (L0056),Y
        EOR     L0040
        STA     L0040
        INY
.LC760
        LDA     LC0FC
        BPL     LC760

        EOR     LCA47,X
        STA     (L0056),Y
        EOR     L0040
        STA     L0040
        INY
.LC76F
        LDA     LC0FC
        BPL     LC76F

        EOR     LCA57,X
        STA     (L0056),Y
        EOR     L0040
        STA     L0040
        INY
        BNE     LC782

        INC     L0057
.LC782
        LDX     L0059
.LC784
        LDA     LC0FC
        BPL     LC784

        EOR     LCA37,X
        STA     (L0056),Y
        EOR     L0040
        STA     L0040
        INY
.LC793
        LDA     LC0FC
        BPL     LC793

        EOR     LCA47,X
        STA     (L0056),Y
        EOR     L0040
        STA     L0040
        INY
.LC7A2
        LDA     LC0FC
        BPL     LC7A2

        EOR     LCA57,X
        STA     (L0056),Y
        EOR     L0040
        STA     L0040
        INY
        DEC     L004B
        BEQ     LC7B8

        JMP     LC72B

.LC7B8
        LDA     LC0FC
        BPL     LC7B8

        STA     L0059
        PLA
        STA     L004B
.LC7C2
        LDA     LC0FC
        BPL     LC7C2

        SEC
        ROL     A
        AND     L0059
        EOR     L0040
.LC7CD
        LDY     LC0FC
        BPL     LC7CD

        CPY     #$C8
        BNE     LC7F2

        LDX     L004C
        BEQ     LC7E2

        LDY     #$00
.LC7DC
        EOR     (L0054),Y
        INY
        DEX
        BNE     LC7DC

.LC7E2
        TAX
        BNE     LC7F6

        LDA     LC0FD
.LC7E8
        LDA     LC0FE
        BMI     LC7E8

        LDA     LC0F0
        CLC
        RTS

.LC7F2
        LDA     #$20
        BNE     LC7F8

.LC7F6
        LDA     #$10
.LC7F8
        SEC
        RTS

; PC=C7FA INVALID opcode FF
        BRK
        BRK
        BRK
; PC=C7FE INVALID opcode BF
        ASL     A
.LC800
        JSR     LCAEE

        JSR     LCA05

        LDY     #$07
        JSR     LCBA9

        LDA     LC08B,X
        LDA     LC089,X
        LDY     #$32
.LC813
        LDA     LC08E,X
        BMI     LC81F

        DEY
        BNE     LC813

        SEC
        JMP     LC949

.LC81F
        LDA     LC081,X
        LDY     #$05
        LDA     #$FF
        STA     LC08F,X
.LC829
        LDA     LC950,Y
.LC82C
        ASL     LC08C,X
        BCC     LC82C

        STA     LC08D,X
        DEY
        BPL     LC829

        LDA     L005A
        ORA     #$80
        JSR     LC9D8

        JSR     LC9D6

        LDA     L005B
        JSR     LC9D8

        JSR     LC9D6

        JSR     LC9D6

        LDA     L004C
        ORA     #$80
        JSR     LC9D8

        LDA     L004B
        ORA     #$80
        JSR     LC9D8

        LDA     L004C
        BEQ     LC873

        LDY     #$FF
        LDA     L0059
.LC862
        ASL     LC08C,X
        BCC     LC862

        STA     LC08D,X
        INY
        LDA     (L0054),Y
        ORA     #$80
        CPY     L004C
        BCC     LC862

.LC873
        LDA     L004B
        BNE     LC87A

        JMP     LC913

.LC87A
        NOP
        LDY     #$00
.LC87D
        LDA     L0041
        STA     LC08D,X
        LDA     L004D
        ORA     #$80
        STY     L0059
.LC888
        LDY     LC08C,X
        BPL     LC888

        STA     LC08D,X
        LDY     L0059
        LDA     (L0056),Y
        STA     L004D
        ASL     A
        ROL     L0041
        INY
        BNE     LC8A1

        INC     L0057
        JMP     LC8A3

.LC8A1
        PHA
        PLA
.LC8A3
        LDA     #$02
        ORA     L0041
        STA     L0041
        LDA     L004E
        ORA     #$80
        STA     LC08D,X
        LDA     (L0056),Y
        STA     L004E
        ASL     A
        ROL     L0041
        INY
        LDA     L004F
        ORA     #$80
        STA     LC08D,X
        LDA     (L0056),Y
        STA     L004F
        ASL     A
        ROL     L0041
        INY
        LDA     L0050
        ORA     #$80
        STA     LC08D,X
        LDA     (L0056),Y
        STA     L0050
        ASL     A
        ROL     L0041
        INY
        BNE     LC8DD

        INC     L0057
        JMP     LC8DF

.LC8DD
        PHA
        PLA
.LC8DF
        LDA     L0051
        ORA     #$80
        STA     LC08D,X
        LDA     (L0056),Y
        STA     L0051
        ASL     A
        ROL     L0041
        INY
        LDA     L0052
        ORA     #$80
        STA     LC08D,X
        LDA     (L0056),Y
        STA     L0052
        ASL     A
        ROL     L0041
        INY
        LDA     L0053
        ORA     #$80
        STA     LC08D,X
        LDA     (L0056),Y
        STA     L0053
        ASL     A
        ROL     L0041
        INY
        DEC     L004B
        BEQ     LC913

        JMP     LC87D

.LC913
        LDA     L0040
        ORA     #$AA
.LC917
        LDY     LC08C,X
        BPL     LC917

        STA     LC08D,X
        LDA     L0040
        LSR     A
        ORA     #$AA
        JSR     LC9D8

        LDA     #$C8
        JSR     LC9D8
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

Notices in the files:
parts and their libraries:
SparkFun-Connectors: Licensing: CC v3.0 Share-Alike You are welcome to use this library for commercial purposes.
